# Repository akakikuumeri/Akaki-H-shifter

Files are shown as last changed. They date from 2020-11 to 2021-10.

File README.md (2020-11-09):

# Akaki-H-shifter
## 3D printable H-pattern shifter for racing simulators.



Highly printable: only external hardware needed is M3 bolts and nuts, two rubber bands, 5 pcs PCB style microswitches, and a compatible Arduino-like microcontroller.

Improved version of my [older 6 speed gear shift](https://www.thingiverse.com/thing:3881165), now with 8 speeds and better spring action. Instead of a simple rubber band and a PLA spring, it uses two cam elements for centering force and latch action. These were lessons learnt from my [joystick project](https://www.thingiverse.com/thing:4576634).

It uses an Arduino Micro for USB HID compliant gamepad support. No drivers required on Windows and Mac OS. Works great with Dirt Rally, Truck Simulator, Assetto Corsa, etc.

Video and build instructions: https://youtu.be/fTknGo8n0Co

Also includes a simple analog handbrake. You need a generic potentiometer. Mount the pot in the base piece, then slip on the shaft and the grip, and tension it with a rubber band.

Connect the potentiometer to your arduino 5V, GND and A0. I used a detachable connector. The source code has a feature where if the pot is not connected at start-up, it ignores the signal.

## Bill of Materials:
* Arduino Pro Micro
* PCB size microswitches, 5pcs
* M3 nuts and bolts (20 mm and 30 mm or other similar lengths)
* 2 Rubber bands
* 2 Desk clamps (I used two ebay microphone clamps)

For handbrake:
* Generic rotational potentiometer (any resistance value will work)

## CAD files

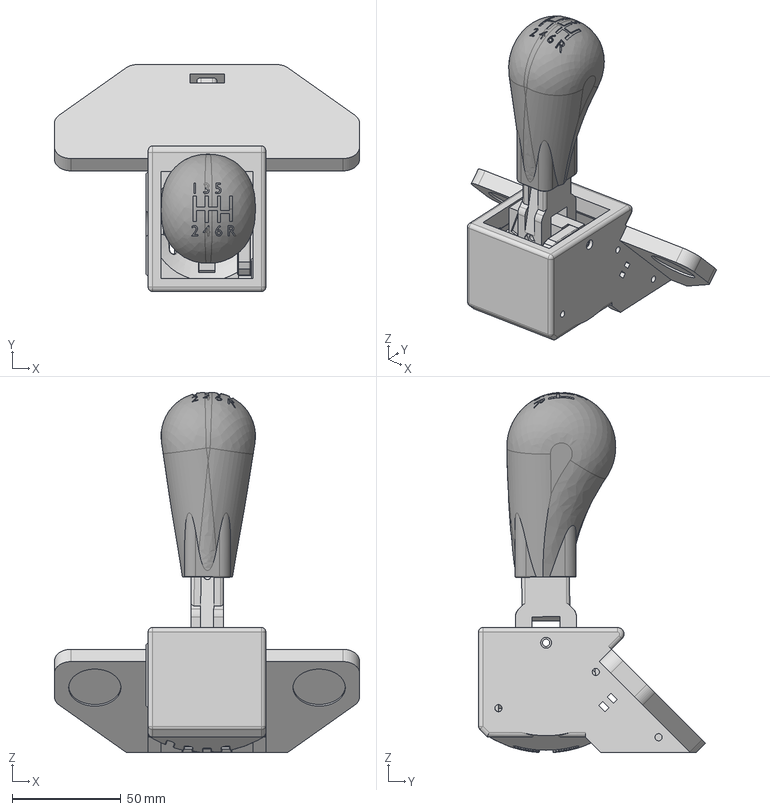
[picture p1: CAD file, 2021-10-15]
h shifter 2.step
140.0 x 104.1 x 165.2 mm
shaft
hinge
hinge cam slider
base
new cam slider
knob
gear x 7
reverse

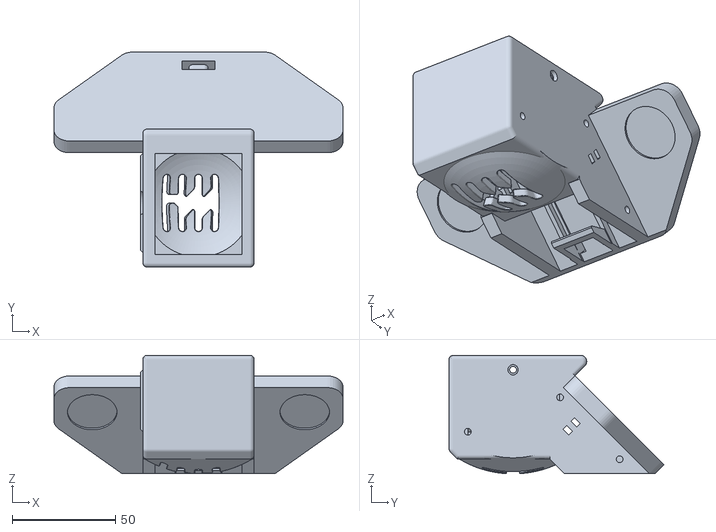
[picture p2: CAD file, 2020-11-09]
Body.stl
140.0 x 104.1 x 57.3

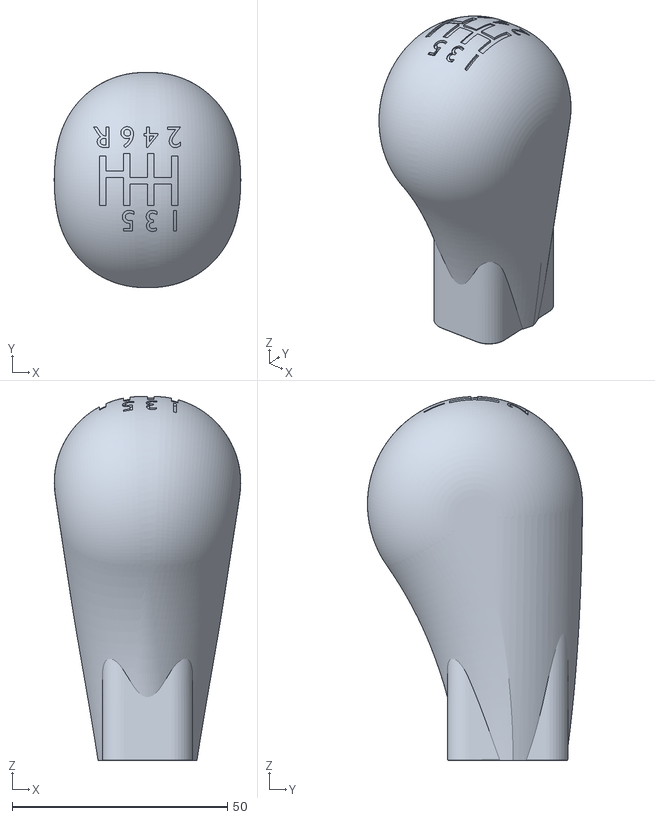
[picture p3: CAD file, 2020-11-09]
knob.stl
43.4 x 50.0 x 84.6

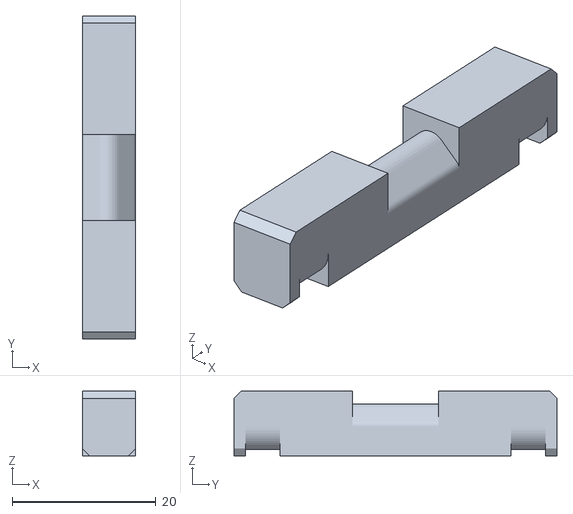
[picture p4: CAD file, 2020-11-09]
left right cam slider.stl
7.40 x 45.0 x 9.00

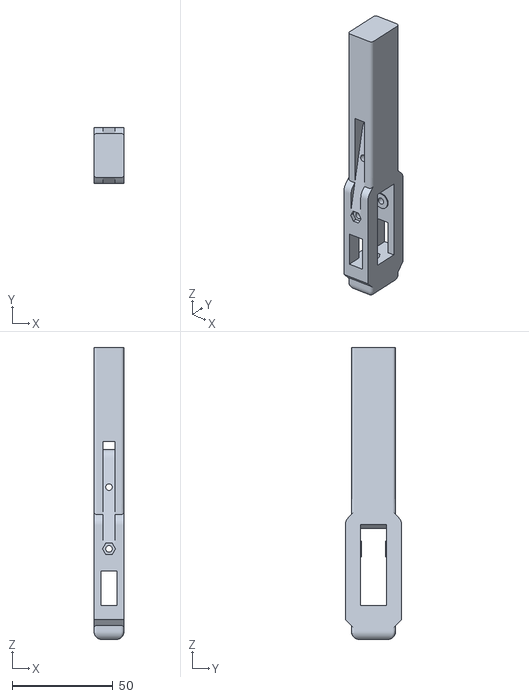
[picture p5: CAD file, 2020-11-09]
shaft.stl
15.0 x 28.0 x 145.0

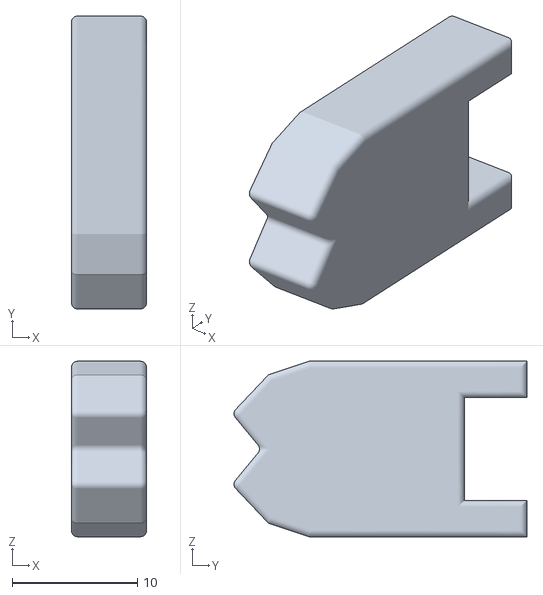
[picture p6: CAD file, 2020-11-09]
hinge cam - glue onto hinge.stl
6.00 x 23.4 x 14.0

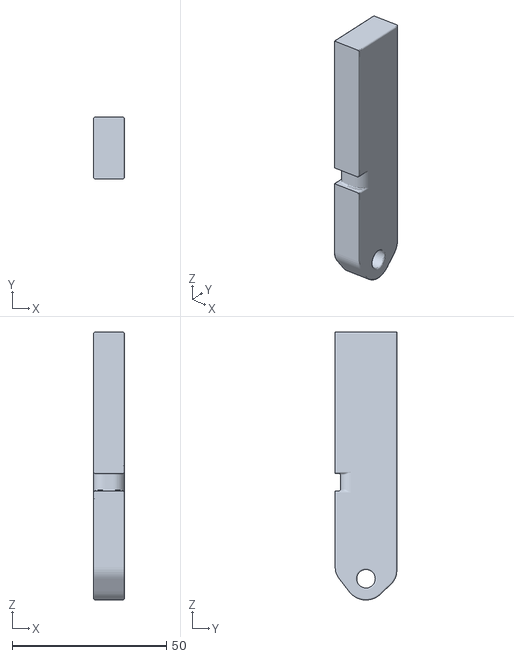
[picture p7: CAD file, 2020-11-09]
handbrake shaft.stl
10.0 x 20.0 x 86.9

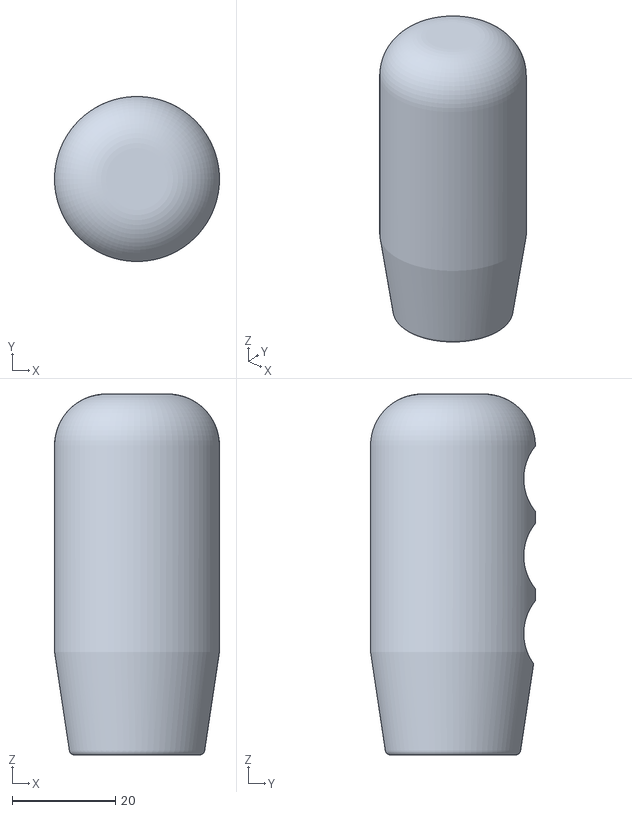
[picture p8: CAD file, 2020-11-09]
handbrake grip.stl
32.0 x 32.0 x 70.0

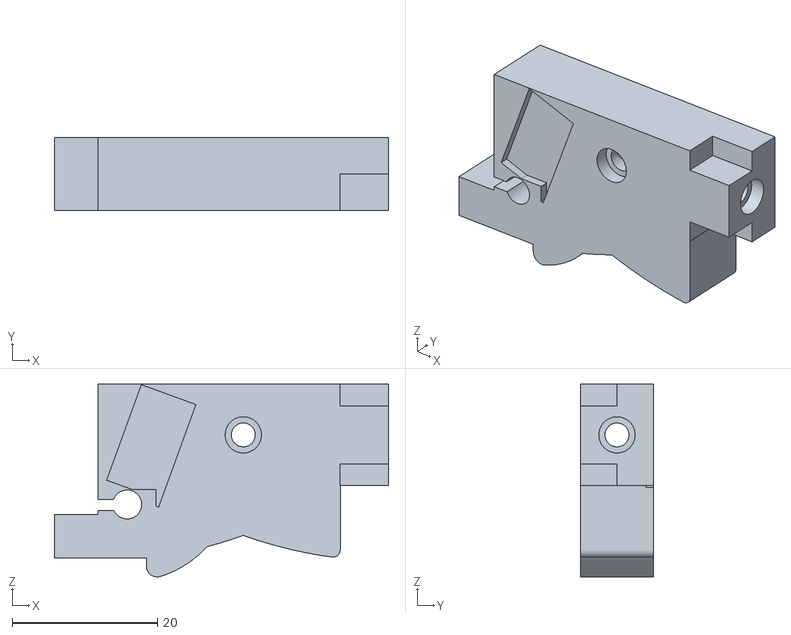
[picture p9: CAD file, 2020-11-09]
hinge.stl
46.0 x 10.0 x 26.6

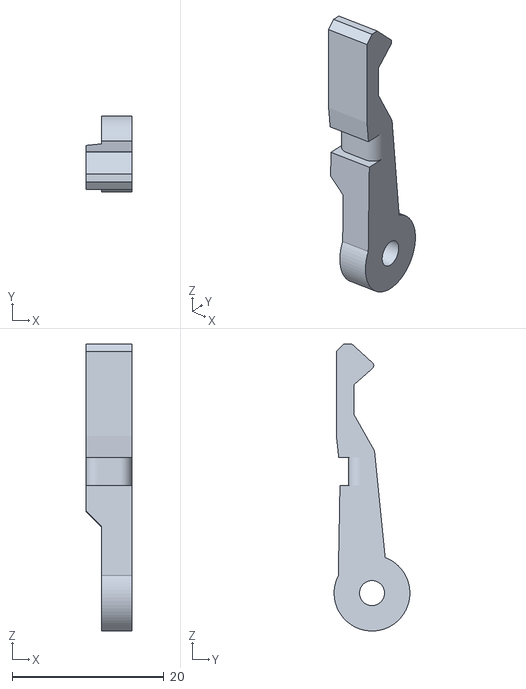
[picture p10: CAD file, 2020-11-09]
up down rachet.stl
6.00 x 10.00 x 37.8

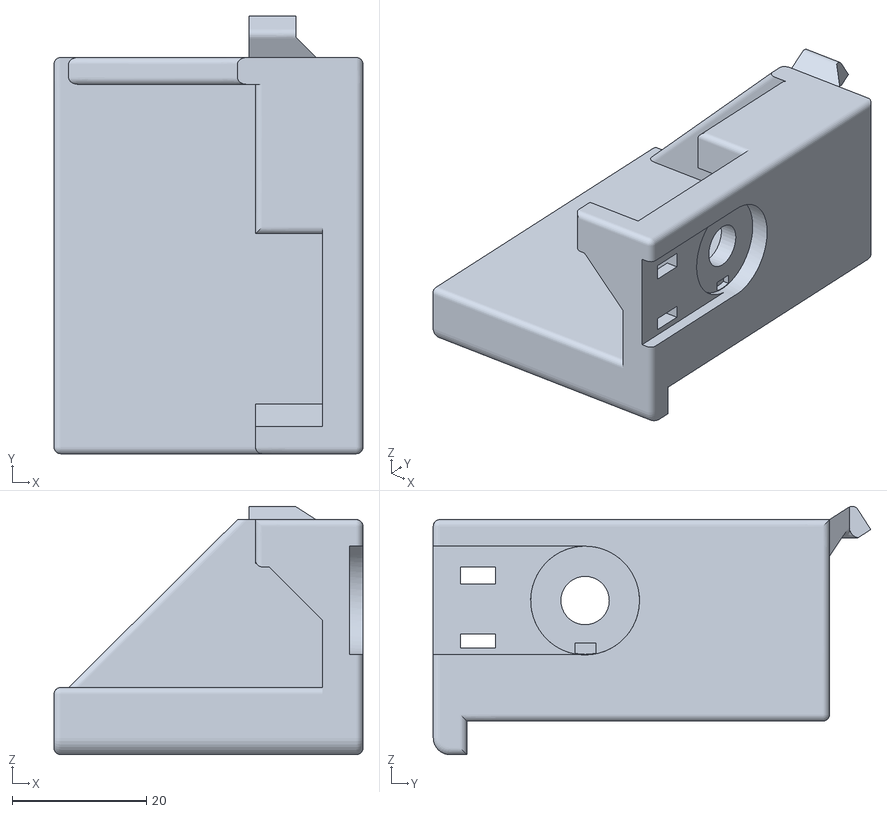
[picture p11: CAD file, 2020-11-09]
handbrake base.stl
46.0 x 65.1 x 37.0

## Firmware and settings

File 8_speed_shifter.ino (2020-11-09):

// 8 speed H shifter using 4 switches, by Akaki Kuumeri 
//Pins
// 2: X left
// 3: X right
// 4: X right extreme
// 5: X up
// 6: Y down

#define LEFT 0
#define RIGHT 1
#define RIGHTEXTREME 2
#define UP 3
#define DOWN 4

#include <Joystick.h>

Joystick_ Joystick(JOYSTICK_DEFAULT_REPORT_ID,JOYSTICK_TYPE_GAMEPAD,
  8, 0,                  // Button Count, Hat Switch Count
  false, false, false,   // No X, Y, Z Axis
  false, false, false,   // No Rx, Ry, or Rz
  false, false,          // No rudder or throttle
  false, false, false);  // No accelerator, brake, or steering

void setup() {
  // Initialize Button Pins
  pinMode(2, INPUT_PULLUP);
  pinMode(3, INPUT_PULLUP);
  pinMode(4, INPUT_PULLUP);
  pinMode(5, INPUT_PULLUP);
  pinMode(6, INPUT_PULLUP);
  pinMode(7, INPUT_PULLUP);

  // Initialize Joystick Library
  Joystick.begin();

}

// Last state of the buttons
int lastButtonState[8] = {0,0,0,0,0,0,0,0};
int currentButtonState[8] = {0,0,0,0,0,0,0,0};
int input[5] = {0,0,0,0,0};
int gear = 0; //0 is neutral

void loop() {

  // Read pin values
  for (int index = 0; index < 5; index++)
  {
    input[index] = !digitalRead(index+2);
  }
  gear = 0;
  if (input[UP]) //if stick is up
  {
    if (input[LEFT]) //left
    {
      gear = 1;
    }
    else if (input[RIGHT])
    {
      if (input[RIGHTEXTREME]) //if also right extreme
      {
        gear = 7;
      }
      else
      {
      gear = 5;
      }
    }
    else
    {
      gear = 3; //stick is neither left not right, but points up
    }
  }
  else if (input[DOWN])
  {
    if (input[LEFT])
    {
      gear = 2;
    }
    else if (input[RIGHT])
    {
      if (input[RIGHTEXTREME]) //if also right extreme
      {
        gear = 8;
      }
      else
      {
      gear = 6;
      }
    }
    else
    {
      gear = 4; //stick is neither left not right, but points down
    }
  } //otherwise 0, neutral

  //make all buttons 0
  currentButtonState[0] = 0;
  currentButtonState[1] = 0;
  currentButtonState[2] = 0;
  currentButtonState[3] = 0;
  currentButtonState[4] = 0;
  currentButtonState[5] = 0;
  currentButtonState[6] = 0;
  currentButtonState[7] = 0;
  if (gear != 0) {currentButtonState[gear-1] = 1;} //if in gear, make button number gear-1 active. First gear is 0, second is 1 and so on
  
  for (int index = 0; index < 8; index++) //send out button comands
  {
    if (currentButtonState[index] != lastButtonState[index])
    {
      Joystick.setButton(index, currentButtonState[index]);
      lastButtonState[index] = currentButtonState[index];
    }
  }

  delay(10);
}
